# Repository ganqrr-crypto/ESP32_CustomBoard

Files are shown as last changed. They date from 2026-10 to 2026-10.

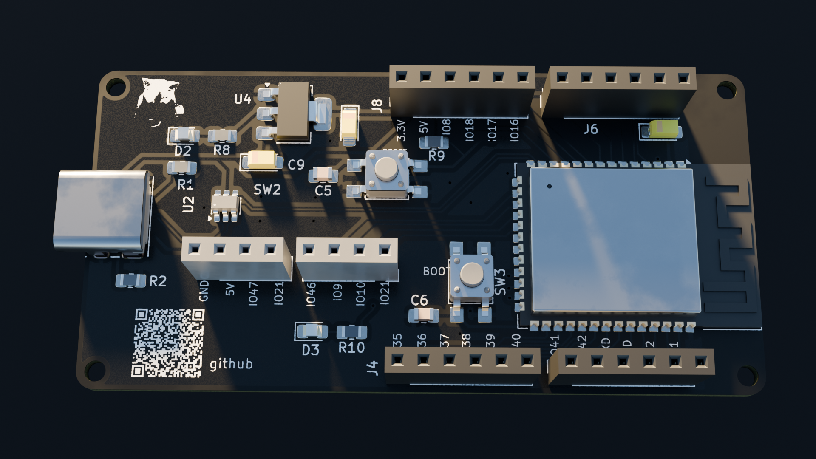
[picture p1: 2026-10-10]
Board/PCB.png

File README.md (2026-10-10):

# ESP32_CustomBoard

This is a ESP32 custom board project that i made/i am making for Half Life by Hack club 

This Board uses the ESP32-S3-WROOM1-N8 as the microcontroller and it  featuresan app on windows that lets you turn on a led and off..

It features a enclosure too



PCB

Schematics:




Model: 



PCB :




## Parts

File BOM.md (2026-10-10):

# ESP_32_Dev_Board – bill of materials

<!-- Generated by Half Life from project cmux32uje00jk01notuwkltv6. Edits here are overwritten on the next sync. -->
<!-- Generated: 2026-10-10T18:07:31.649Z -->

> [!NOTE]
> This parts list is mirrored from [Half Life](https://halflife.hackclub.com). Editing it here will not change the platform's copy, and the next sync overwrites this file.

| Week | Tier | Parts funding |
| --- | --- | --- |
| Week 1 | Tier 1 | $30.00 |

| Part | What it's for | Qty | Unit | Total | Vendor |
| --- | --- | --- | --- | --- | --- |
| [10 uF Tantalum Capacitor](https://www.lcsc.com/it/product-detail/C7171.html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) | Capacitors | 1 | $0.31 | $0.31 | [LCSC ELECTRONICS](https://www.lcsc.com/it/product-detail/C7171.html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) |
| [22 uF Tantalum](https://www.lcsc.com/it/product-detail/C11366.html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) | Capacitors | 1 | $0.62 | $0.62 | [LCSC ELECTRONICS](https://www.lcsc.com/it/product-detail/C11366.html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) |
| [ESP32-S3 WROOM-1-N8](https://www.lcsc.com/it/product-detail/C2913198.html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) | Microcontroller | 1 | $5.06 | $5.06 | [LCSC ELECTRONICS](https://www.lcsc.com/it/product-detail/C2913198.html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) |
| [0.1uF Capacitor](https://www.lcsc.com/it/product-detail/C49678.html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) | Capacitors | 1 | $0.39 | $0.39 | [LCSC ELECTRONICS](https://www.lcsc.com/it/product-detail/C49678.html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) |
| [LED](https://www.lcsc.com/it/product-detail/C2297.html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) | Power Led | 1 | $0.85 | $0.85 | [LCSC ELECTRONICS](https://www.lcsc.com/it/product-detail/C2297.html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) |
| [USB-C Port](https://www.lcsc.com/it/search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) | Usb Port | 1 | $1.46 | $1.46 | [LCSC ELECTRONICS](https://www.lcsc.com/it/search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) |
| [Connector 4 Pin](https://www.lcsc.com/it/product-detail/C42163122.html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) | Pins | 1 | $0.49 | $0.49 | [LCSC ELECTRONICS](https://www.lcsc.com/it/product-detail/C42163122.html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) |
| [Connector 6 Pin](https://www.lcsc.com/it/product-detail/C42431861.html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) | Pins | 1 | $0.38 | $0.38 | [LCSC ELECTRONICS](https://www.lcsc.com/it/product-detail/C42431861.html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) |
| [5.1k Resistors](https://www.lcsc.com/it/product-detail/C27834.html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) | Resistor | 1 | $0.58 | $0.58 | [LCSC ELECTRONICS](https://www.lcsc.com/it/product-detail/C27834.html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) |
| [10K Resistors](https://www.lcsc.com/it/product-detail/C2907219.html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) | Resistor | 1 | $0.36 | $0.36 | [LCSC ELECTRONICS](https://www.lcsc.com/it/product-detail/C2907219.html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) |
| [Buttons](https://www.lcsc.com/it/product-detail/C36938886.html) | RESET and BOOT | 1 | $0.99 | $0.99 | [LCSC ELECTRONICS](https://www.lcsc.com/it/product-detail/C36938886.html) |
| [ESD](https://www.lcsc.com/it/product-detail/C2827654.html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) | ESD | 1 | $0.46 | $0.46 | [LCSC ELECTRONICS](https://www.lcsc.com/it/product-detail/C2827654.html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) |
| [3.3v regulator](https://www.lcsc.com/it/product-detail/C6186.html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) | 3.3 Regulation | 1 | $1.09 | $1.09 | [LCSC ELECTRONICS](https://www.lcsc.com/it/product-detail/C6186.html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) |
| [PCB](https://jlcpcb.com/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) | PCB | 1 | $3.93 | $3.93 | [JLCPCB](https://jlcpcb.com/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) |
| **Parts subtotal** | — | — | — | **$16.97** | — |
| **Tax & shipping** | — | — | — | **$14.57** | — |
| **Total** | — | — | — | **$31.54** | — |

**$1.54 over the tier's funding.** Every tier gives a fixed amount for parts, so this needs cutting back or a higher tier.

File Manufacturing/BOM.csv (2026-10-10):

Name | Purpose | Quantity | Total Cost (USD) | Links | Vendor | Shipping Components | Total Components + Shipping
10 uF Tantalum Capacitor | Capacitors | 2 | $0.31 | link | LCSC ELECTRONICS | $11 + $3.36(Handling Fee) | $32.13
22 uF Tantalum | Capacitors | 2 | $0.62 | link | LCSC ELECTRONICS
ESP32-S3 WROOM-1-N8 | Microcontroller | 1 | $5.06 | link | LCSC ELECTRONICS
0.1uF Capacitor | Capacitors | 20 | $0.39 | link | LCSC ELECTRONICS
LED | Power Led | 50 | $0.85 | link | LCSC ELECTRONICS
USB-C Port | Usb Port | 1 | $1.46 | link | LCSC ELECTRONICS
Connector 4 Pin | Pins | 5 | $0.49 | link | LCSC ELECTRONICS
Connector 6 Pin | Pins | 19 | $0.38 | link | LCSC ELECTRONICS
5.1k Resistors | Resistor | 100 | $0.58 | link | LCSC ELECTRONICS
10K Resistors | Resistor | 100 | $0.36 | link | LCSC ELECTRONICS
Buttons | RESET and BOOT | 5 | $1.58 | link | LCSC ELECTRONICS
ESD | ESD | 10 | $0.46 | link | LCSC ELECTRONICS
3.3v regulator | 3.3 Regulation | 5 | $1.09 | link | LCSC ELECTRONICS
PCB | PCB | 5 | $3.93 | link | JLCPCB

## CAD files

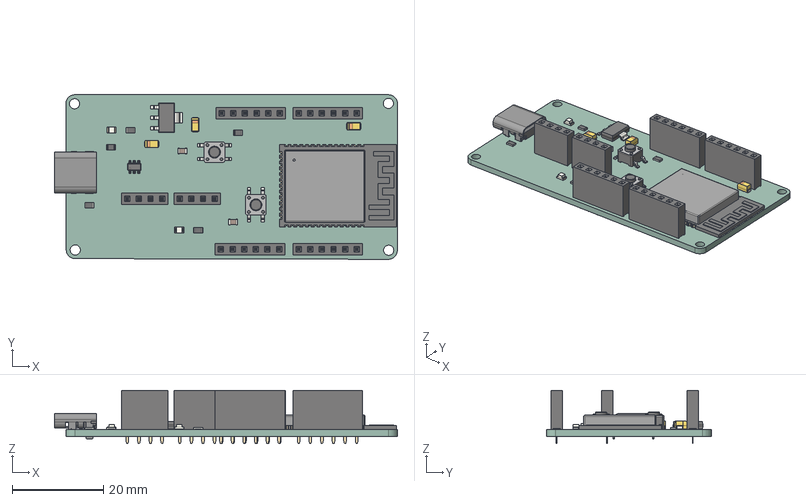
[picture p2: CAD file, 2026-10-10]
Board/esp_32_board.step
75.0 x 36.0 x 11.6 mm
CP_EIA_3216_18_Kemet_A x 3
PinSocket_1x06_P2.54mm_Vertical x 4
C_0805_2012Metric x 2
PinSocket_1x04_P2.54mm_Vertical x 2
USB_C_Receptacle_GCT_USB4085
R_0805_2012Metric x 5
SW_SPST_TL3305A x 2
LED_0805_2012Metric x 2
ESP32-S3-WROOM-1
SOT-23-6
SOT-223
esp_32_board_PCB

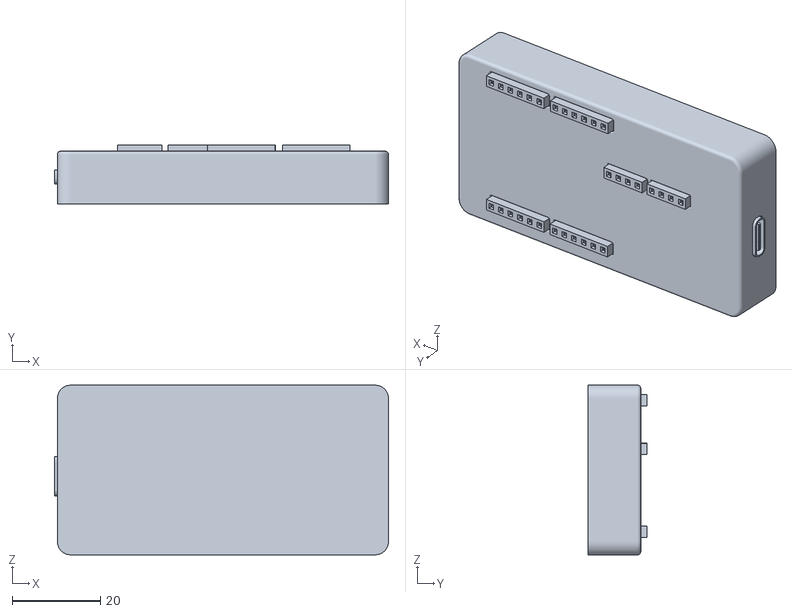
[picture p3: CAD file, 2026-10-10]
Manufacturing/ESP_32_CASE.stl
75.7 x 13.4 x 38.5

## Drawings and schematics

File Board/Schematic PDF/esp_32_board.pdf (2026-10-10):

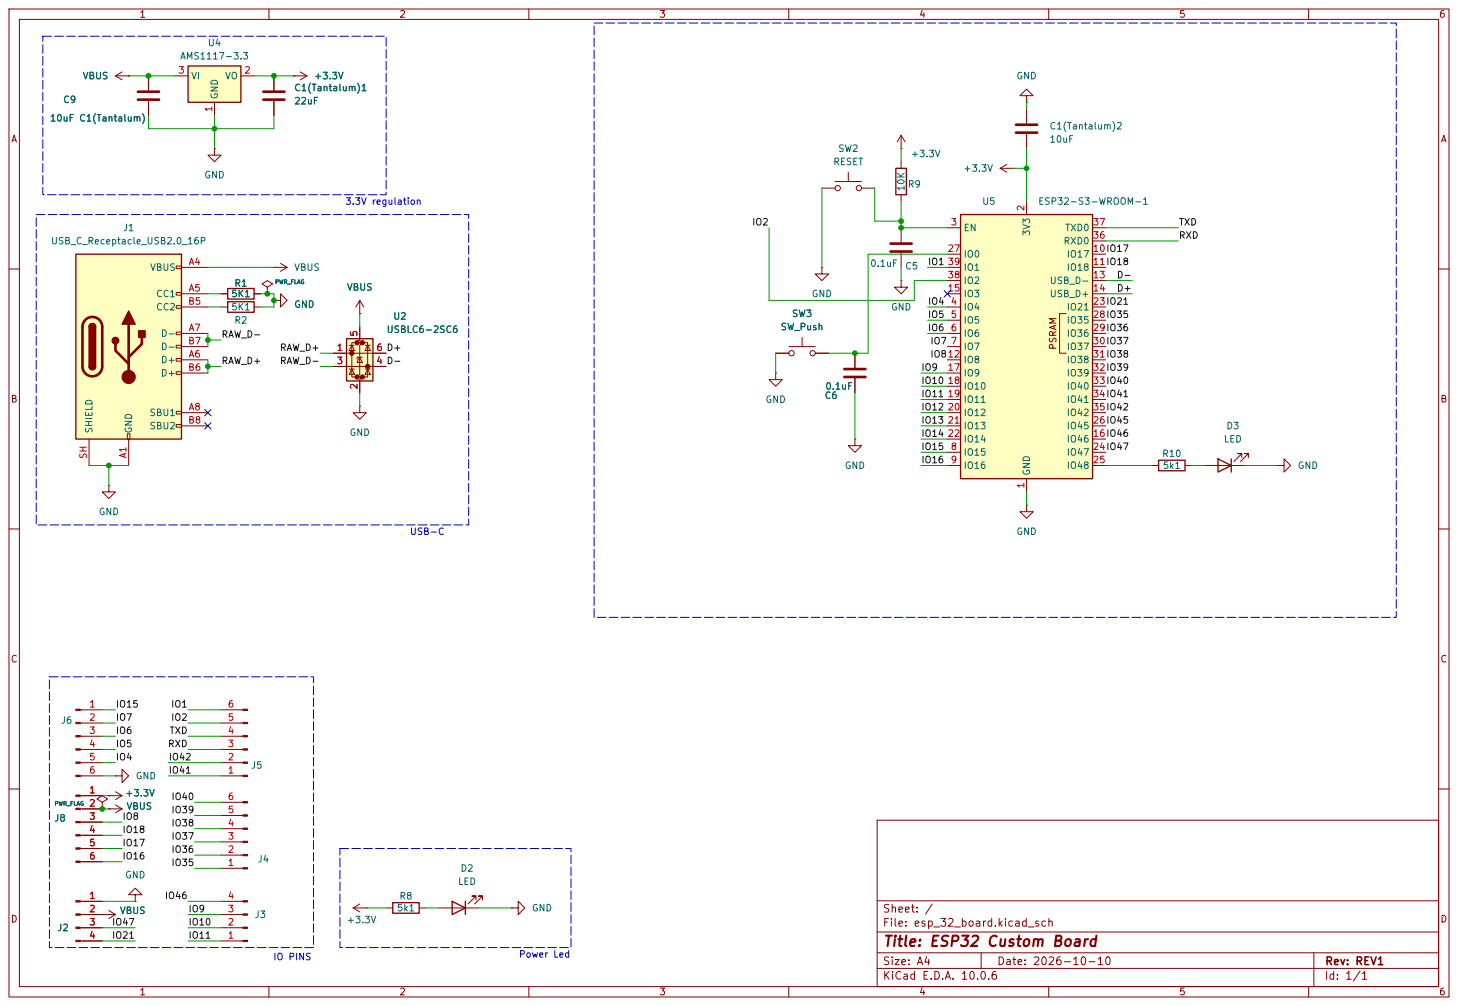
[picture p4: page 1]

Size: A4 | Rev: REV1
KiCad E.D.A. 10.0.6 | Id: 1/1

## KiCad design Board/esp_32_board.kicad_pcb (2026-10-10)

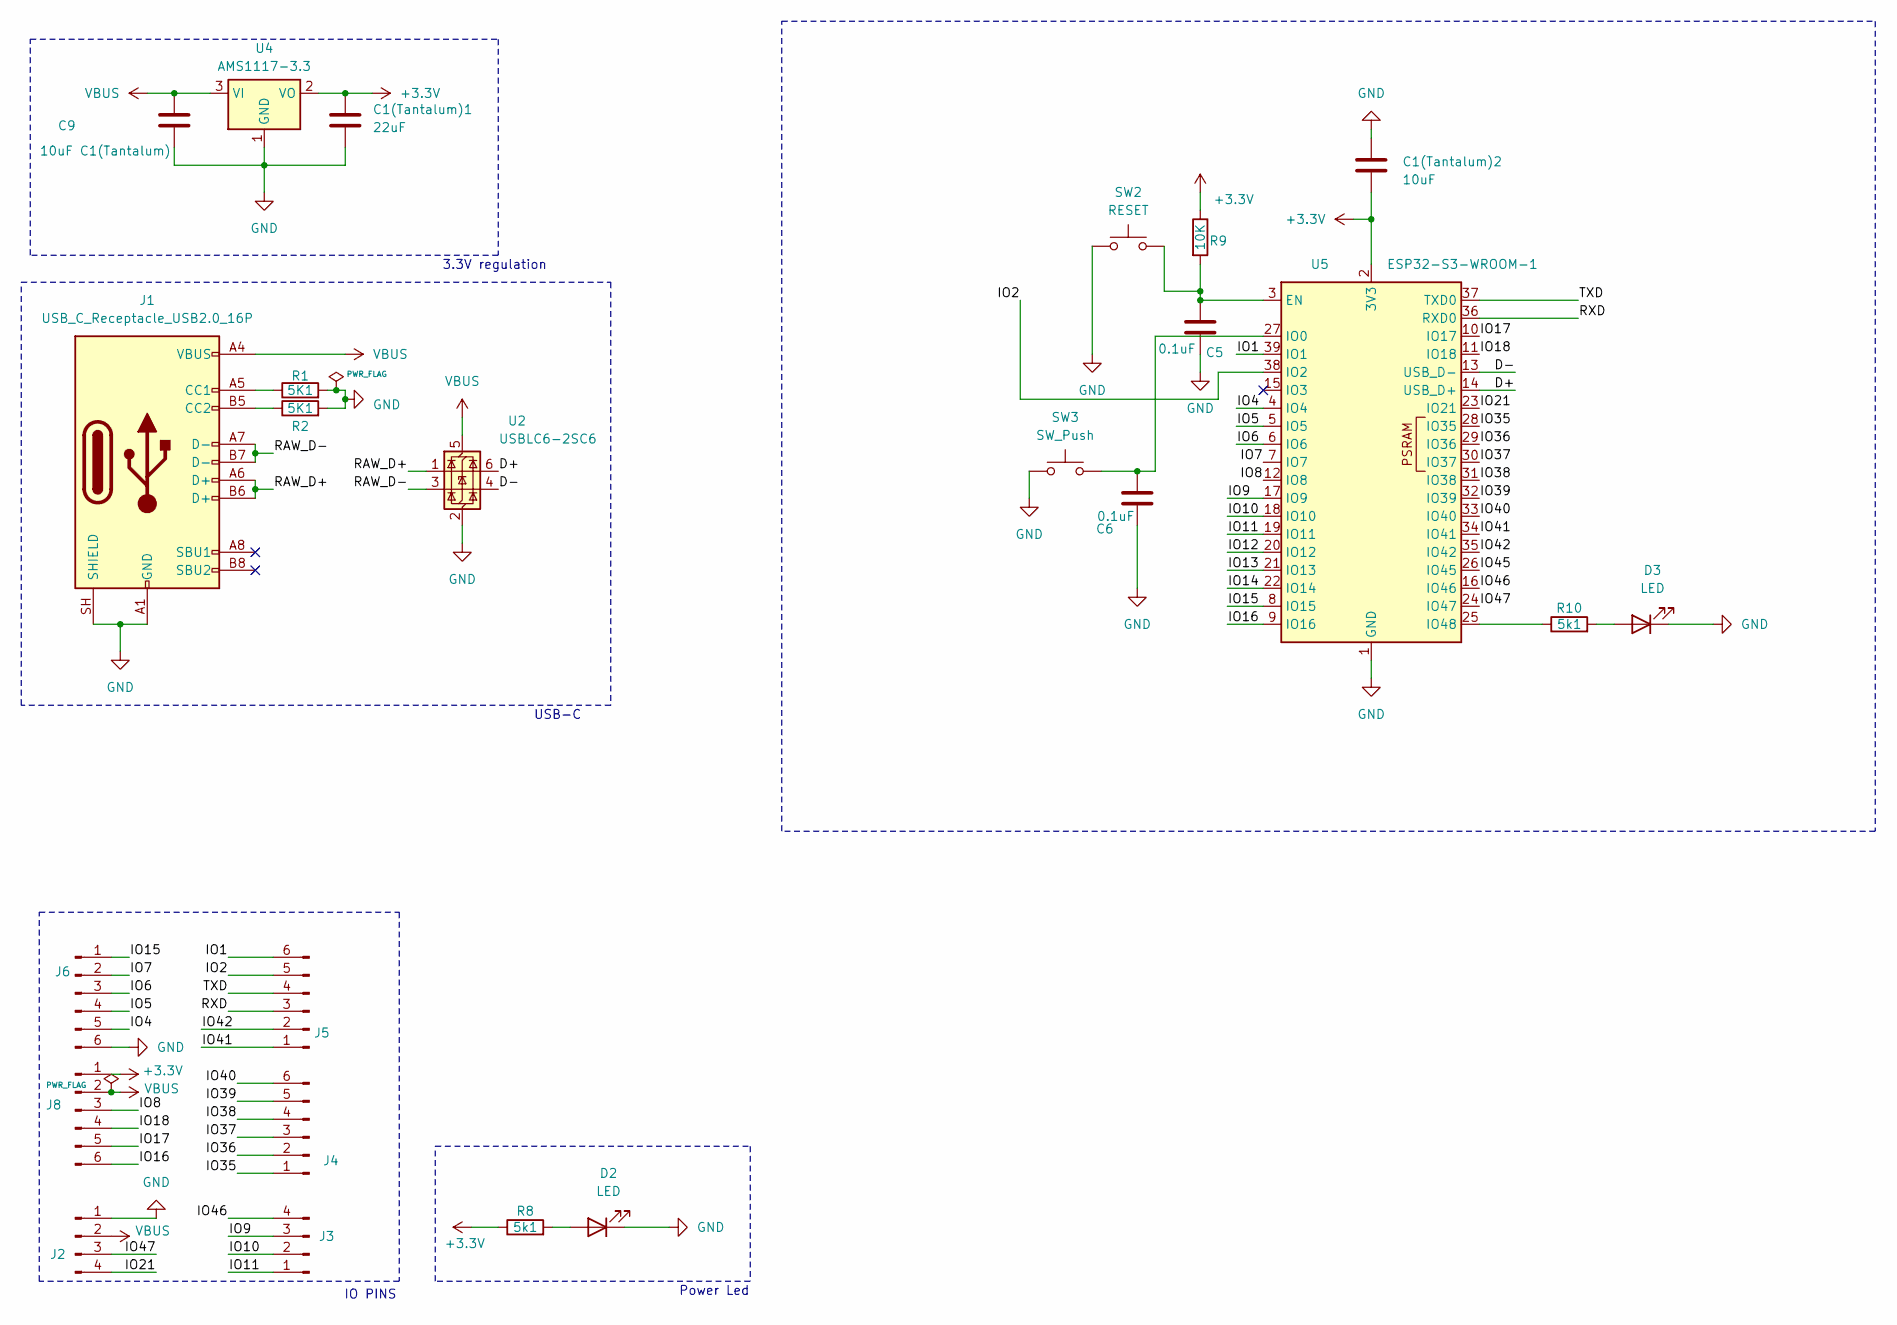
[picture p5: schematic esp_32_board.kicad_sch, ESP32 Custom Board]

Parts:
C1(Tantalum)1: 22uF; CP_EIA-3216-18_Kemet-A_HandSolder
C1(Tantalum)2: 10uF; CP_EIA-3216-18_Kemet-A_HandSolder
C5, C6: 0.1uF; C_0805_2012Metric_Pad1.18x1.45mm_HandSolder
C9: 10uF C1(Tantalum); CP_EIA-3216-18_Kemet-A_HandSolder
D2, D3: LED; LED_0805_2012Metric_Pad1.15x1.40mm_HandSolder
J1: USB_C_Receptacle_USB2.0_16P; USB_C_Receptacle_GCT_USB4085
J2: UART; PinSocket_1x04_P2.54mm_Vertical
J3: JTAG; PinSocket_1x04_P2.54mm_Vertical
J4, J5, J6, J8: Conn_01x06_Pin; PinSocket_1x06_P2.54mm_Vertical
R1, R2: 5K1; R_0805_2012Metric_Pad1.20x1.40mm_HandSolder
R8, R10: 5k1; R_0805_2012Metric_Pad1.20x1.40mm_HandSolder
R9: 10K; R_0805_2012Metric_Pad1.20x1.40mm_HandSolder
SW2: RESET; SW_SPST_TL3305A
SW3: SW_Push; SW_SPST_TL3305A
U2: USBLC6-2SC6; SOT-23-6
U4: AMS1117-3.3; SOT-223-3_TabPin2
U5: ESP32-S3-WROOM-1

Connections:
+3.3V: C1(Tantalum)1.1, C1(Tantalum)2.2, J8.1, R8.1, R9.1, U4.2 (VO), U5.2 (3V3)
/D+: U2.6 (I/O1), U5.14 (USB_D+)
/D-: U2.4 (I/O2), U5.13 (USB_D-)
/IO1: J5.6, U5.39 (IO1)
/IO2: J5.5, U5.38 (IO2)
/IO4: J6.5, U5.4 (IO4)
/IO5: J6.4, U5.5 (IO5)
/IO6: J6.3, U5.6 (IO6)
/IO7: J6.2, U5.7 (IO7)
/IO8: J8.3, U5.12 (IO8)
/IO9: J3.3, U5.17 (IO9)
/IO10: J3.2, U5.18 (IO10)
/IO11: J3.1, U5.19 (IO11)
/IO12: U5.20 (IO12)
/IO13: U5.21 (IO13)
/IO14: U5.22 (IO14)
/IO15: J6.1, U5.8 (IO15)
/IO16: J8.6, U5.9 (IO16)
/IO17: J8.5, U5.10 (IO17)
/IO18: J8.4, U5.11 (IO18)
/IO21: J2.4, U5.23 (IO21)
/IO35: J4.1, U5.28 (IO35)
/IO36: J4.2, U5.29 (IO36)
/IO37: J4.3, U5.30 (IO37)
/IO38: J4.4, U5.31 (IO38)
/IO39: J4.5, U5.32 (IO39)
/IO40: J4.6, U5.33 (IO40)
/IO41: J5.1, U5.34 (IO41)
/IO42: J5.2, U5.35 (IO42)
/IO45: U5.26 (IO45)
/IO46: J3.4, U5.16 (IO46)
/IO47: J2.3, U5.24 (IO47)
/RAW_D+: J1.A6 (D+), J1.B6 (D+), U2.1 (I/O1)
/RAW_D-: J1.A7 (D-), J1.B7 (D-), U2.3 (I/O2)
/RXD: J5.3, U5.36 (RXD0)
/TXD: J5.4, U5.37 (TXD0)
GND: C1(Tantalum)1.2, C1(Tantalum)2.1, C5.1, C6.1, C9.2, D2.1 (K), D3.1 (K), J1.A1 (GND), J1.A12 (GND), J1.B1 (GND), J1.B12 (GND), J1.SH (SHIELD), J2.1, J6.6, R1.2, R2.2, SW2.1, SW3.1, U2.2 (GND), U4.1 (GND), U5.1 (GND), U5.40 (GND), U5.41 (GND)
unnamed: D2.2 (A), R8.2
unnamed: D3.2 (A), R10.2
unnamed: J1.A5 (CC1), R1.1
unnamed: J1.B5 (CC2), R2.1
unnamed: C5.2, R9.2, SW2.2, U5.3 (EN)
unnamed: C6.2, SW3.2, U5.27 (IO0)
unnamed: R10.1, U5.25 (IO48)
VBUS: C9.1, J1.A4 (VBUS), J1.A9 (VBUS), J1.B4 (VBUS), J1.B9 (VBUS), J2.2, J8.2, U2.5 (VBUS), U4.3 (VI)

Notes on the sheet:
3.3V regulation
IO PINS
Power Led
USB-C

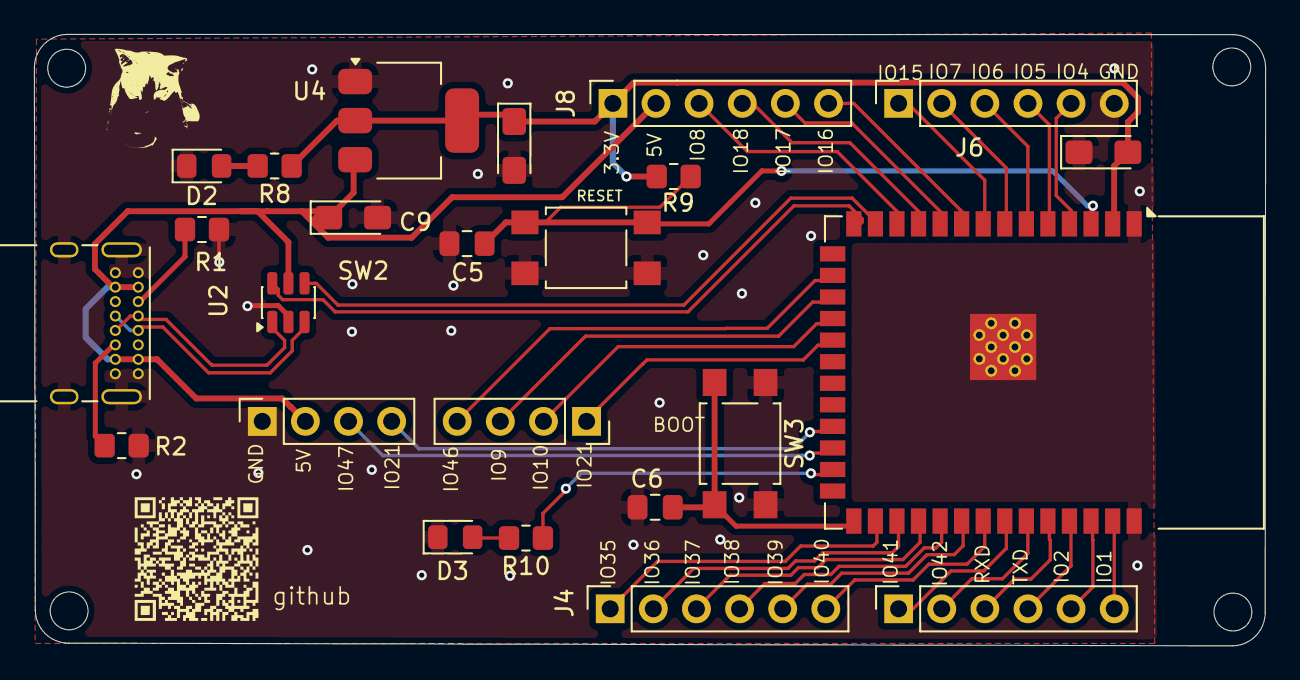
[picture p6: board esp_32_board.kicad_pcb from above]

Board: 2 copper layers, 72.5 x 36.0 mm, 24 parts (0 on the bottom side), 41 nets.

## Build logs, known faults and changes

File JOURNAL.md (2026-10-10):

# ESP_32_Dev_Board – devlog

<!-- Generated by Half Life from project cmux32uje00jk01notuwkltv6. Edits here are overwritten on the next sync. -->
<!-- Generated: 2026-10-10T17:42:16.842Z -->

> [!NOTE]
> This devlog is mirrored from [Half Life](https://halflife.hackclub.com). Editing it here will not change the platform's copy, and the next sync overwrites this file.

> A custom ESP32 board

| Week | Tier | Hours logged | Entries |
| --- | --- | --- | --- |
| Week 1 | Tier 1 | 16.43h | 11 |

## Contents

1. [2026-10-06 – Work session](#2026-10-06-work-session)
2. [2026-10-07 – Finished the schematics](#2026-10-07-finished-the-schematics)
3. [2026-10-07 – Work session](#2026-10-07-work-session)
4. [2026-10-08 – PCB and Schematics](#2026-10-08-pcb-and-schematics)
5. [2026-10-08 – Work session](#2026-10-08-work-session)
6. [2026-10-09 – Work session](#2026-10-09-work-session)
7. [2026-10-09 – Work session](#2026-10-09-work-session)
8. [2026-10-10 – Work session](#2026-10-10-work-session)
9. [2026-10-10 – Work session](#2026-10-10-work-session)
10. [2026-10-10 – Work session](#2026-10-10-work-session)
11. [2026-10-10 – Work session](#2026-10-10-work-session)

## Design

### 2026-10-06 – Work session

**1h**

[Timelapse](https://lookout.hackclub.com/api/media/73e6279f-9f50-4838-9eaa-e3d2f042125b/video.mp4)

### 2026-10-07 – Finished the schematics

**1.22h**

Finished the schematics

[Timelapse](https://lookout.hackclub.com/api/media/4170937c-b246-4fcf-b3e4-320e5d4f867e/video.mp4)

### 2026-10-07 – Work session

**3.32h**

[Timelapse](https://lookout.hackclub.com/api/media/723d8447-8ab2-42dc-8b86-65703b32ffb9/video.mp4)

### 2026-10-08 – PCB and Schematics

**1.57h**

PCB and Schematics

[Timelapse](https://lookout.hackclub.com/api/media/3d8e90e2-fee5-4cae-918f-efa93682754f/video.mp4)

### 2026-10-08 – Work session

**2.1h**

[Timelapse](https://lookout.hackclub.com/api/media/7a53597a-4d8b-4da4-b58c-5605348d207a/video.mp4)

### 2026-10-09 – Work session

**3.02h**

[Timelapse](https://lookout.hackclub.com/api/media/9d09ae94-1bd2-45b4-a650-52ebe9861984/video.mp4)

### 2026-10-09 – Work session

**0.55h**

[Timelapse](https://lookout.hackclub.com/api/media/cb4d7656-9640-4e25-9531-38eaf4b559e2/video.mp4)

### 2026-10-10 – Work session

**0.97h**

[Timelapse](https://lookout.hackclub.com/api/media/c7380baa-c557-43a9-8854-75aad89e2500/video.mp4)

### 2026-10-10 – Work session

**0.88h**

[Timelapse](https://lookout.hackclub.com/api/media/f468438d-b9e9-4c21-8144-012a00903620/video.mp4)

### 2026-10-10 – Work session

**0.92h**

[Timelapse](https://lookout.hackclub.com/api/media/51494750-cb5e-4976-b037-982502d63994/video.mp4)

### 2026-10-10 – Work session

**0.88h**

[Timelapse](https://lookout.hackclub.com/api/media/d222065b-62aa-412f-8ea7-f5c18e330568/video.mp4)

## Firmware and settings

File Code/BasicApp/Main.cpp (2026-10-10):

#include "raylib.h"
#include "Program.hpp"

int main(){


    int screenWidth = 800;
    int screenHeight = 600;


    SetConfigFlags(FLAG_MSAA_4X_HINT);
    InitWindow(screenWidth, screenHeight, "Basic App for ESP");

    SetTargetFPS(60);

    std::cout << "Starting" << std::endl;


    int ClickCount = 0;
    int Roboto1FontSize = 40;

    Font Roboto1 = LoadFontEx("Roboto1.ttf", Roboto1FontSize, 0, 0);

    ESP32_Program esp32;
    bool ok = esp32.connect("COM2");
    //Ill Modify the COM Port later when ill get the ESP32

    bool isLedOn = false;
    Rectangle LedButton = { 300, 200, 250, 150 };
    Rectangle ExitButton = { 680, 30, 100, 50 };
    Rectangle ReconnectButton = { 620, 500, 150, 75 };
    

    bool isReconnecting = false;
    float ReconnectTimer = 0.0f;

    while(!WindowShouldClose()){


        Vector2 MousePos = GetMousePosition();
        bool isHoveringButton = CheckCollisionPointRec(MousePos, LedButton);
        bool isHoveringExit = CheckCollisionPointRec(MousePos, ExitButton);
        bool isHoveringReconnect = CheckCollisionPointRec(MousePos, ReconnectButton);

        if(IsMouseButtonPressed(MOUSE_BUTTON_LEFT) && isHoveringButton){


            isLedOn = !isLedOn;
            esp32.setLed(isLedOn);
            ClickCount++;

        }

        if(IsMouseButtonPressed(MOUSE_BUTTON_LEFT) && isHoveringExit){

            CloseWindow();

            std::cout << "Exiting" << std::endl;

        }

        if(isHoveringReconnect && IsMouseButtonPressed(MOUSE_BUTTON_LEFT)){

            esp32.connect("COM2");
            //Same here ill modify the com port later
            esp32.setLed(isLedOn);
            isReconnecting = true;
            ReconnectTimer = 1.0f;

            std::cout << "Trying to reconnect..." << std::endl;

        }
    

        if(isReconnecting){
            ReconnectTimer -= GetFrameTime();
            if(ReconnectTimer <= 0.0f){
                isReconnecting = false;
            }
        }

        BeginDrawing();

        ClearBackground(Color{25,28,40,225});



        Color ButtonColor = DARKGRAY;
        if(isHoveringButton){
            ButtonColor = GRAY;
        }

        Color ExitButtonColor = RED;
        if(isHoveringExit){
            ExitButtonColor = MAROON;
        }

        Color ReconnectButtonColor = RED;
        if(isHoveringReconnect){
            ReconnectButtonColor = MAROON;
        }

        DrawTextEx(Roboto1, "ESP32 Led Test App", { 300, 20 }, Roboto1FontSize, 2, RAYWHITE);

        DrawRectangleRounded(LedButton,0.5f, 16, ButtonColor);


        DrawRectangleRounded(ExitButton, 0.5f, 16, ExitButtonColor);
        DrawTextEx(Roboto1, "Exit", { 700, 40 }, Roboto1FontSize, 2, RAYWHITE);

        DrawRectangleRounded(ReconnectButton, 0.5f, 16, ReconnectButtonColor);
        DrawTextEx(Roboto1, "Reconnect", { 630, 520 }, 30, 2, RAYWHITE);

        DrawCircle(50, 50, 40, isLedOn ? GREEN : GRAY);

        DrawTextEx(Roboto1, isLedOn ? "LED ON" : "LED OFF", { 350, 100 }, Roboto1FontSize, 2, isLedOn ? GREEN : RED);

        DrawTextEx(Roboto1, esp32.isConnected() ? "Connected" : "Disconnected", { 320, 400 }, Roboto1FontSize, 2, esp32.isConnected() ? GREEN : RED);
        
        DrawTextEx(Roboto1, "Turn Led On/Off", { 320, 250 }, 35, 2, isLedOn ? GREEN : RED);

        DrawTextEx(Roboto1, TextFormat("Click Count: %i", ClickCount), { 30, 550 }, 30, 2, RAYWHITE);

        if(isReconnecting){
            DrawTextEx(Roboto1, "Reconnecting...", { 400, 500 }, 30, 2, YELLOW);
        }



        EndDrawing();

        
        
    }

    CloseWindow();

    std::cout << "Exiting" << std::endl;

    return 0;


}

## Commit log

2026-10-09 Update README with project details and schematics
    Added project description and schematics images.
2026-10-09 added bom and pcb/schematics
    [BOM.csv, esp_32_board.kicad_pcb, esp_32_board.kicad_sch]
2026-10-09 BOM update
2026-10-10 alot of work
    [esp_32_board-B_Cu.gbr, esp_32_board-B_Mask.gbr, esp_32_board-B_Paste.gbr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]
2026-10-10 Add PCB image to README
    Added an additional PCB image to the README.
2026-10-10 Remove BOM section from README
    Removed BOM section from the README.
2026-10-16 BOM UPDATE 2
2026-10-16 Add BOM section to README
    Added BOM section with location information.
2026-10-17 Fixed the BOM link issue
2026-10-17 Added modifiable case files
2026-10-17 fix to bom and added a note for reveiewer
2026-10-19 Add Bill of Materials and cost summary to README
    Added a detailed Bill of Materials (BOM) section including components, purposes, quantities, costs, vendors, and links to product pages. Also included a cost summary for total components and shipping.
